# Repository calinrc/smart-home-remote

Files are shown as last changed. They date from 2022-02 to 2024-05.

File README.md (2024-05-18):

# smart-home-remote
Smart Home Remote Control

This project tries to facilitate the remote control of some IOT resources deployed localy on my home network.

## Description

The story behind this project is based on several broken Roger H80/TX22 remote controls. These used to control the front gate or garage door.
In many cases I ended up buying new remotes or clones of them due to the fact that the plastic shell of the previous remote controles broke or the battery connection was not stable.

For this reason I decided to dismantle one of the original remotes and link their buttons to some handcrafted circuits that act as basic switches.

The first approach was to use a RasberryPI as a webserver that coordinates the GPIO pins, linked via some octocuplers to the buttons of the remotes. 
Soon I realized that this keeps my RPI 4 linked to this project and I cannot use it anymore to another one, so I decided to replace it with something cheaper. This ended up in the V2 project where I have used an ESP-12F as web server and GPIO controller.

## Components

### Hardware

#### V1
- RaspberryPI (4) (RPI)
- 220 Ohm resistor - 2 pieces
- 10k Ohm resistor - 2 pieces
- PC817 Octocupler  - 2 pieces
- 2N2222A Transistor - 2 peces
- 433 MHz Generic Remote control (2 buttons)

#### V2
- ESP-12F (ESP8266)
- 10k Ohm resistor - 2 pieces
- 100 Ohm resistor - 1 pieces
- 100 uF capacitor - 1 piece
- PC817 Octocupler  - 2 pieces
- 2N2222A Transistor - 2 peces
- 433 MHz Generic Remote control (2 buttons)
- YwRobot Breadboard Power Supply
- 12 V power supply

*** 

## Images for final boards

## Schematics

Schematics for this can be found on [./hardware_schematics/SmartHouseRemote.fzz](./hardware_schematics/SmartHouseRemote.fzz) . The file can be opened using Fritzing Software. 
```bash
sudo apt install fritzing
``` 

## Software used
### V1
- Nodered HTTP service that receives requests from external devices (phone app, web pages) and translates them in GPIO commands for RPI. Check [ ./server/nodered/flows.json ](./server/nodered/flows.json)
- Android phone application preprovisioned with authentication credentials. Check [./client/android/SmartHouseRemote](./client/android/SmartHouseRemote)

### V2
- ESP8266WebServer that receives requests from external devices (phone app, web pages) and translates them in GPIO commands. Check [ ./server/ESPServer/src/main.cpp ](./server/ESPServer/src/main.cpp)
- Android phone application preprovisioned with authentication credentials. Check [./client/android/SmartHouseRemote](./client/android/SmartHouseRemote)

 ### Use case:
Phone application will send HTTP requests to web service to manage warious hardware devices (first scenario is to control the 433 Mhz Roger remote control)

## Software Installation

### V1 - RaspberryPI 
- Raspberry Pi OS Lite - https://www.raspberrypi.com/software/operating-systems/
- Nodered for RPI - see https://nodered.org/docs/getting-started/raspberrypi

Changes made to default Raspbian OS
- Install nodered on
     ```bash
     sudo apt update
     sudo apt install nodered
     ```
- Install nodered as service
    ```bash
    sudo systemctl enable nodered.service
    ```
- generate credentials for admin and default user
    ```bash
    node-red admin hash-pw
    ```
- Update nodered admin and user credentials
   - update `~/.node-red/settings.js` with generated password on following places
    ```json

    adminAuth: {
        type: "credentials",
        users: [{
            username: "admin",
            password: "generated_passwd_here",
            permissions: "*"
        }]
    },    

    ...

    httpNodeAuth: {user:"some_user_here",pass:"generated_passwd_here"},

    ```

### V2
- ESP-12F - ESP8266 Arduino Firmware
- Libraries
    - ESP8266WebServer
    - ArduinoOTA
    - ESP8266WiFi

## Credits:

- Gaven MacDonald - for its tutorial about octocuplers and transistors https://youtu.be/pYENAGK8qH4
- Indrek Luuk - for ESP wiring and programming tutorials https://circuitjournal.com/esp8266-with-arduino-ide
- Andreas Spiess for its tutorial on power supplies https://youtu.be/DLQ1E5pDcBU
- https://fritzing.org - for their PCB editor

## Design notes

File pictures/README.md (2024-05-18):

## Pictures of anssambled board

- YwRobot Breadboard (Top Right)
- ESP12-F + Expansion Board (Top Left - Whithe board)
- Roger H80/TX22 board (Bottom Center) 
- Single Layer Perfboard

Schematics

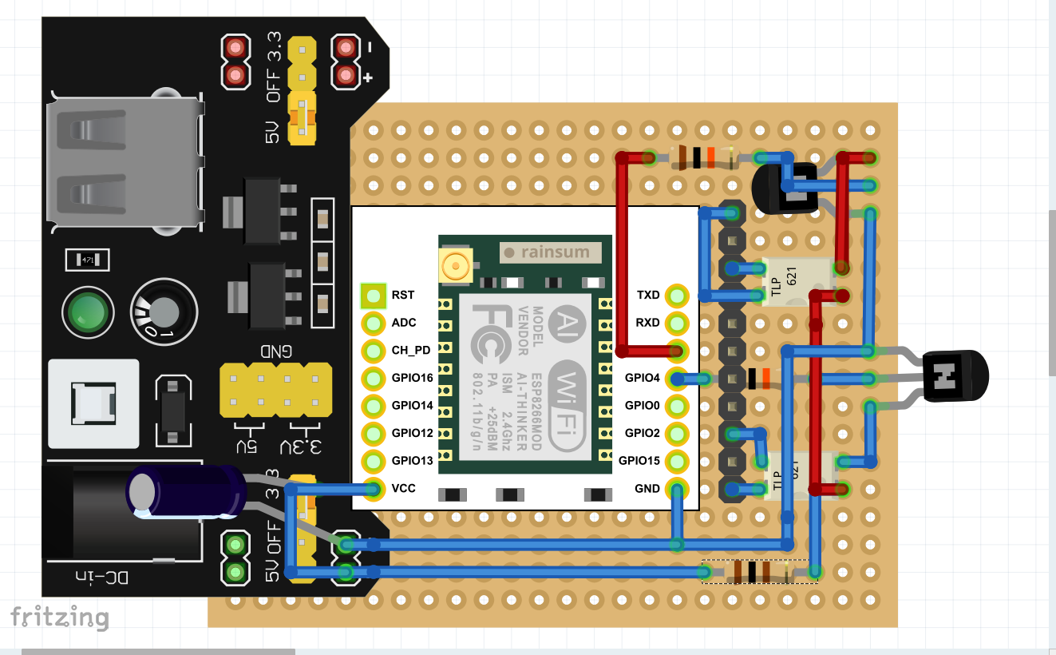
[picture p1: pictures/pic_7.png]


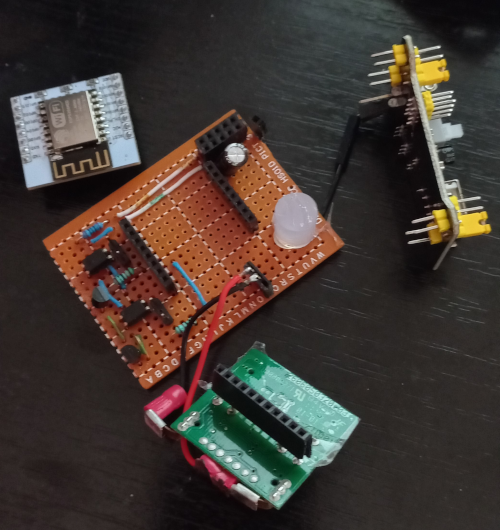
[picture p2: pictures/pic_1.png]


The ESP-12F was mounted in some female header jumper connectors soldiered on perfboard
Note: Current used by Roger remote is 12 Volts so it requires a distinct rail linked directly to 12V power supply.

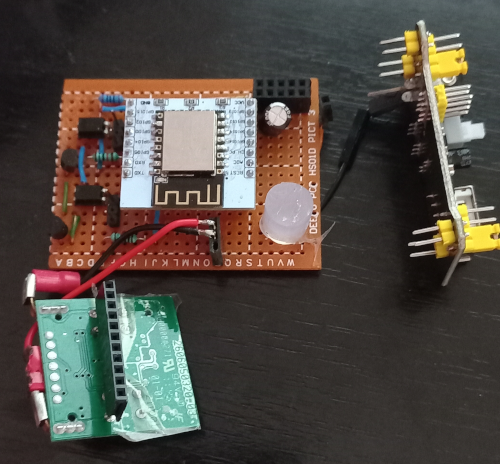
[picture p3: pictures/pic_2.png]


YwRobot Breadboard was mounted as well in some female header jumper connectors  

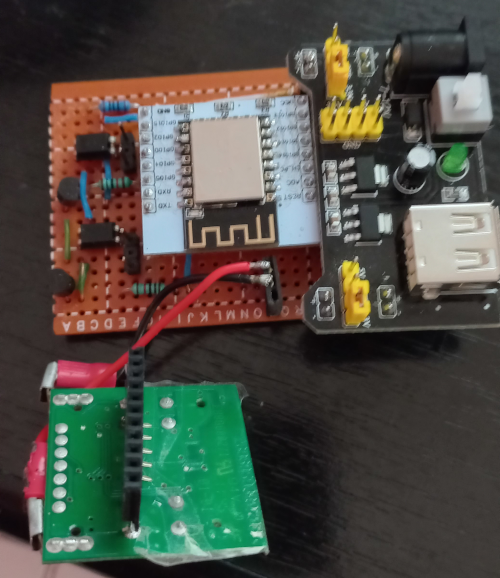
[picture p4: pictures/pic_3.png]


Mounted Roger 433 Mhz remote board.

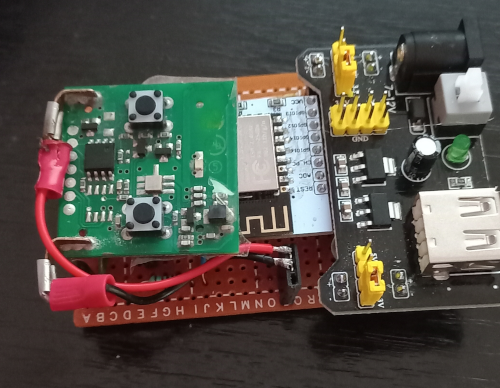
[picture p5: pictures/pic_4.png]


Back image of perfboard.

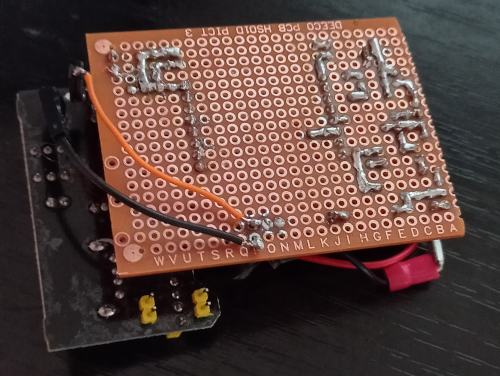
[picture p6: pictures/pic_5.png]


The entire circuit was was monted in some plastic box bought from local electric store. 

The drawings are made by my son. :) 

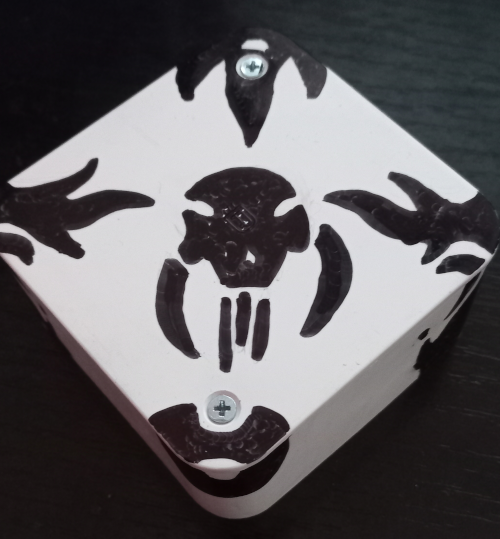
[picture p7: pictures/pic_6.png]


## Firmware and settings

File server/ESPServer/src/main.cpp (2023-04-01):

#include <ESP8266WiFi.h>
#include <ESP8266WebServer.h>
#include <ArduinoOTA.h>
#include "definitions.h"
#include "constants.h"
#include "config_utils.h"

IPAddress AP_IP = IPAddress(10, 1, 1, 1);
IPAddress AP_subnet = IPAddress(255, 255, 255, 0);

WifiConf wifiConf;
bool cold_start = false;

// Web server for editing configuration.
// 80 is the default http port.
ESP8266WebServer server(1880);

static const uint8_t GATE_PIN = D1;
static const uint8_t DOOR_PIN = D2;

bool connectToWiFi();
void setUpAccessPoint();
void setUpWebServer(bool coldStart);
void setUpOverTheAirProgramming(bool coldStart);

void handleColdStateWebServerRequest();
void handleStateGet();
void handleChangeStateGate();
void handleChageStateDoor();

void setup()
{
  Serial.begin(9600);
  Serial.println("Booting...");
  pinMode(LED_BUILTIN, OUTPUT);
  pinMode(GATE_PIN, OUTPUT);
  pinMode(DOOR_PIN, OUTPUT);

  // init wifiConfig
  // to read/write wifi configuration.
  initConf(&wifiConf);
  readWifiConf(&wifiConf);
  Serial.printf("Try connect to configured accesspoint \"%s\" \n", wifiConf.wifi_ssid);
  Serial.printf("Webserver username \"%s\" \n", wifiConf.ws_username);

  if (!connectToWiFi())
  {
    cold_start = true;
    setUpAccessPoint();
  }
  setUpWebServer(cold_start);
  setUpOverTheAirProgramming(cold_start);
  digitalWrite(LED_BUILTIN, HIGH);
  Serial.printf("Cold start %d \n", cold_start);
  Serial.println("Setup completed ...");

}

bool connectToWiFi()
{
  Serial.printf("Connecting to '%s'\n", wifiConf.wifi_ssid);

  WiFi.mode(WIFI_STA);
  WiFi.begin(wifiConf.wifi_ssid, wifiConf.wifi_password);
  if (WiFi.waitForConnectResult() == WL_CONNECTED)
  {
    Serial.print("Connected. IP: ");
    Serial.println(WiFi.localIP());
    return true;
  }
  else
  {
    Serial.println("Connection Failed!");
    return false;
  }
}

void setUpAccessPoint()
{
  Serial.println("Setting up access point.");
  Serial.printf("SSID: %s\n", AP_ssid);
  Serial.printf("Password: %s\n", AP_password);

  WiFi.mode(WIFI_AP_STA);
  WiFi.softAPConfig(AP_IP, AP_IP, AP_subnet);
  if (WiFi.softAP(AP_ssid, AP_password))
  {
    Serial.print("Ready. Access point IP: ");
    Serial.println(WiFi.softAPIP());
  }
  else
  {
    Serial.println("Setting up access point failed!");
  }
}

void setUpWebServer(bool coldStart)
{
  if (coldStart)
    server.on("/", handleColdStateWebServerRequest);
  else
  {
    server.on("/home/state", HTTP_GET, handleStateGet);
    server.on("/home/gate", HTTP_PUT, handleChangeStateGate);
    server.on("/home/door", HTTP_PUT, handleChageStateDoor);
  }
  server.begin();
}

void handleColdStateWebServerRequest()
{
  bool save = false;

  if (server.hasArg("ssid") && server.hasArg("password") && server.hasArg("ws_user") && server.hasArg("ws_password"))
  {
    server.arg("ssid").toCharArray(wifiConf.wifi_ssid, sizeof(wifiConf.wifi_ssid));
    server.arg("password").toCharArray(wifiConf.wifi_password, sizeof(wifiConf.wifi_password));
    server.arg("ws_user").toCharArray(wifiConf.ws_username, sizeof(wifiConf.ws_username));
    server.arg("ws_password").toCharArray(wifiConf.ws_password, sizeof(wifiConf.ws_password));
    server.arg("ota_password").toCharArray(wifiConf.ota_password, sizeof(wifiConf.ota_password));

    Serial.println(server.arg("ssid"));
    Serial.println(wifiConf.wifi_ssid);

    Serial.println(server.arg("ws_user"));
    Serial.println(wifiConf.ws_username);

    writeWifiConf(&wifiConf);
    save = true;
  }

  String message = "";
  message += DOC_HEADER;
  if (save)
    message += DOC_REBOOTING;
  else
  {
    String form = String(DOC_FORM);
    form.replace("$SSID", wifiConf.wifi_ssid);
    form.replace("$PASSWORD", wifiConf.wifi_password);
    form.replace("$WSUSER", wifiConf.ws_username);
    form.replace("$WSPASSORD", wifiConf.ws_password);
    form.replace("$OTAPASSORD", wifiConf.ota_password);
    message += form;
  }

  message += DOC_FOOTER;
  server.send(200, "text/html", message);

  if (save)
  {
    Serial.println("Wi-Fi conf saved. Rebooting...");
    delay(1000);
    ESP.restart();
  }
}

void handleStateGet()
{
  String message = STATE_OK_RESP;
  server.send(200, "application/json", message);
}

void handleChangeStateGate()
{
  if (!server.authenticate(wifiConf.ws_username, wifiConf.ws_password))
  {
    return server.requestAuthentication();
  }
  String message = STATE_CHANGED_GATE_RESP;
  server.send(200, "application/json", message);
  digitalWrite(GATE_PIN, HIGH);
  digitalWrite(LED_BUILTIN, LOW);  // turn the LED on (LOW is the voltage level)
  delay(1000);                      // wait for a second
  digitalWrite(GATE_PIN, LOW);
  digitalWrite(LED_BUILTIN, HIGH); // turn the LED off by making the voltage HIGH
}

void handleChageStateDoor()
{
  if (!server.authenticate(wifiConf.ws_username, wifiConf.ws_password))
  {
    return server.requestAuthentication();
  }
  String message = STATE_CHANGED_DOOR_RESP;
  server.send(200, "application/json", message);
  digitalWrite(DOOR_PIN, HIGH);
  digitalWrite(LED_BUILTIN, LOW);  // turn the LED on (LOW is the voltage level)
  delay(1000);                     // wait for a second
  digitalWrite(DOOR_PIN, LOW);
  digitalWrite(LED_BUILTIN, HIGH); // turn the LED off by making the voltage HIGH

}

void setUpOverTheAirProgramming(bool coldStart)
{

  // Change OTA port.
  // Default: 8266
  // ArduinoOTA.setPort(8266);

  // Change the name of how it is going to
  // show up in Arduino IDE.
  // Default: esp8266-[ChipID]
  // ArduinoOTA.setHostname("myesp8266");

  // Re-programming passowrd.
  // No password by default.
  if (!cold_start){
    ArduinoOTA.setPassword(wifiConf.ota_password);
  }

  ArduinoOTA.begin();
}

void loop()
{
  // Give processing time for ArduinoOTA.
  // This must be called regularly
  // for the Over-The-Air upload to work.
  ArduinoOTA.handle();

  // Give processing time for the webserver.
  // This must be called regularly
  // for the webserver to work.
  server.handleClient();
  if (cold_start){
    long int since = millis();
    if (since > 3*60*1000){
      Serial.println("More than 3 minutes without any chnages in wifi settings. Rebooting...");
      delay(1000);
      ESP.restart();
    }
  }
  
}

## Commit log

2021-11-29 Add hardware schematics
    [SmartHouseRemote.fzz]
2022-01-15 fix: working ota upload
    [main.cpp]
2022-01-23 update internal LED default state to HIGH for NO light mode
2022-02-03 update OTA upload
    [SmartHouseRemoteESP.fzz]
2022-02-05 update schematics for ESP
    [SmartHouseRemoteESP.fzz]
2022-02-18 add images of final circuit
2022-10-04 fix: update gradle and kotlin versions
    [automotive_app_desc.XML]
2022-10-18 feat: align button horizontally
2023-04-01 fix: handle case when local network restarts after ESP
    [main.cpp]
